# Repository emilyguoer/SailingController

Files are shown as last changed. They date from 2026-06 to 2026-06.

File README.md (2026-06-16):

## What is this project?

This project is a sailing boat controller. It uses a 3D printed boat model to simulate the rudder movement of a real sailing boat. The controller uses an M5Stack Atom as the main controller. Its built-in LED shows different states, such as Bluetooth connection, game mode, and calibration mode. Each M5Stack Chain Angle sensor is mounted inside a 3D printed boat shell.

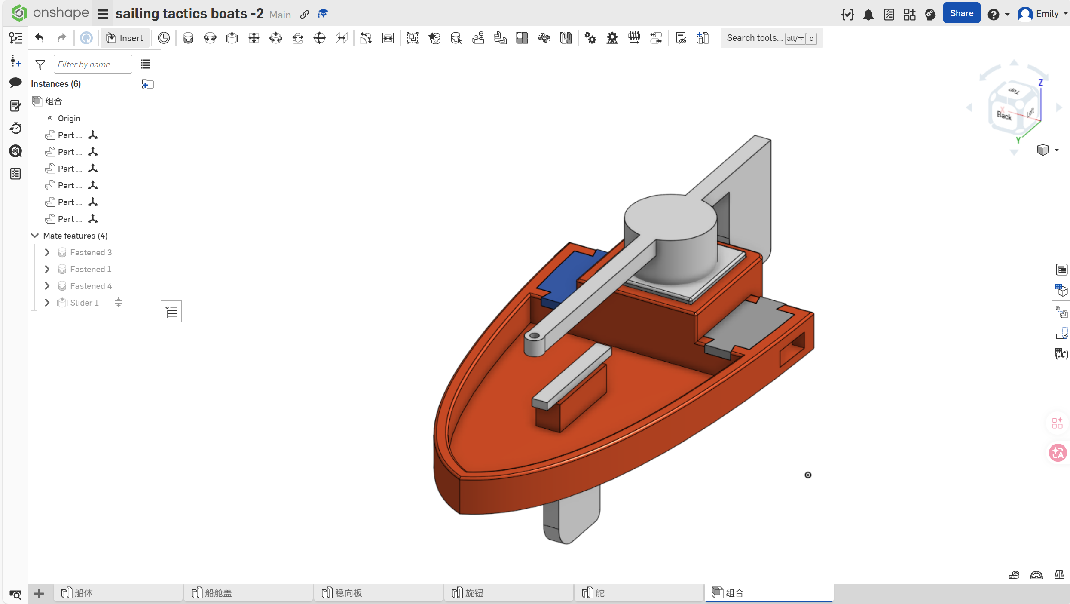
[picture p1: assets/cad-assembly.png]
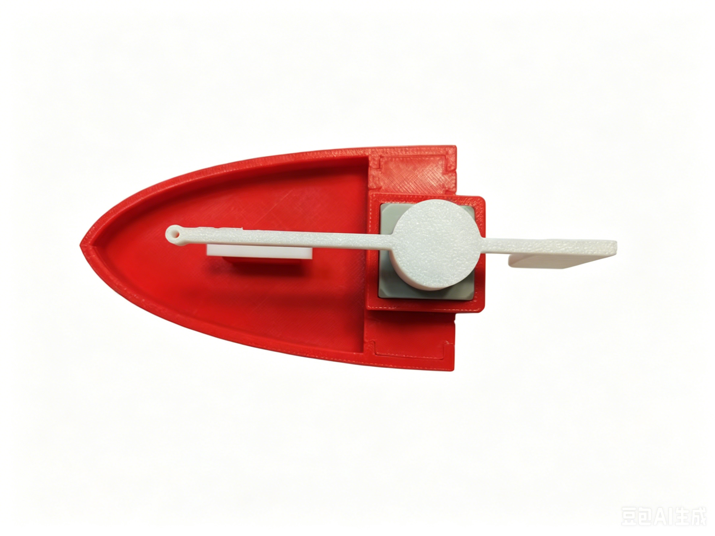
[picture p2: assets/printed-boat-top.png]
  

The M5Stack Chain Angle sensors work as the boat rudders. They read the rudder angle and convert the movement into keyboard inputs for Tactical Sailing.

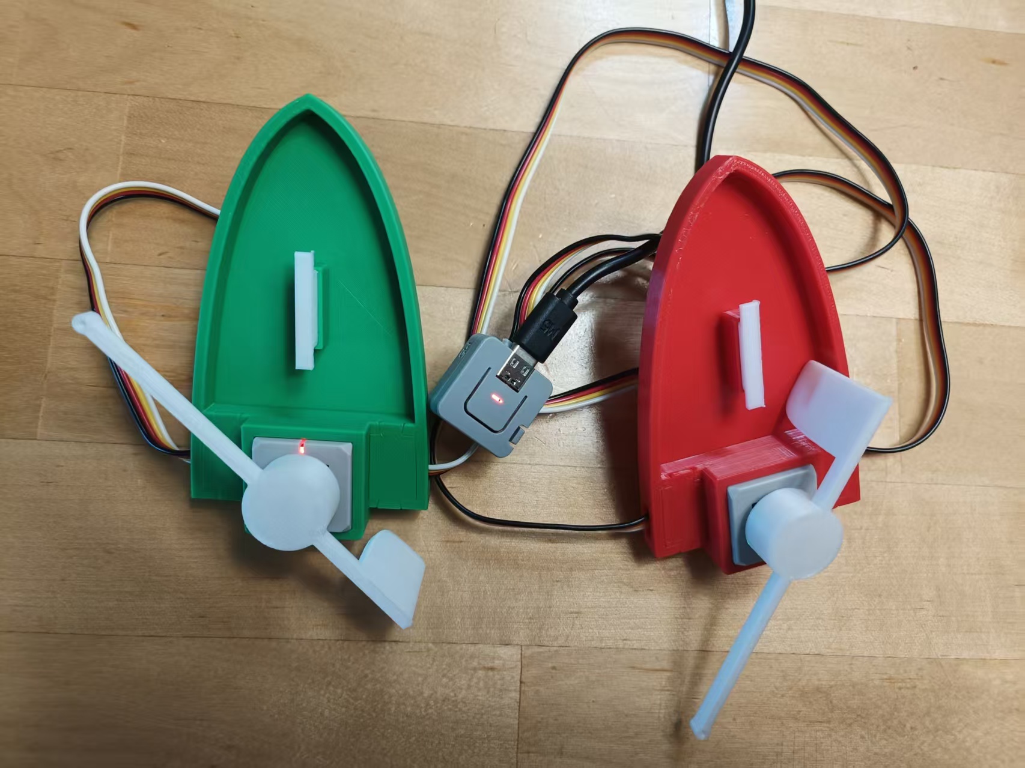
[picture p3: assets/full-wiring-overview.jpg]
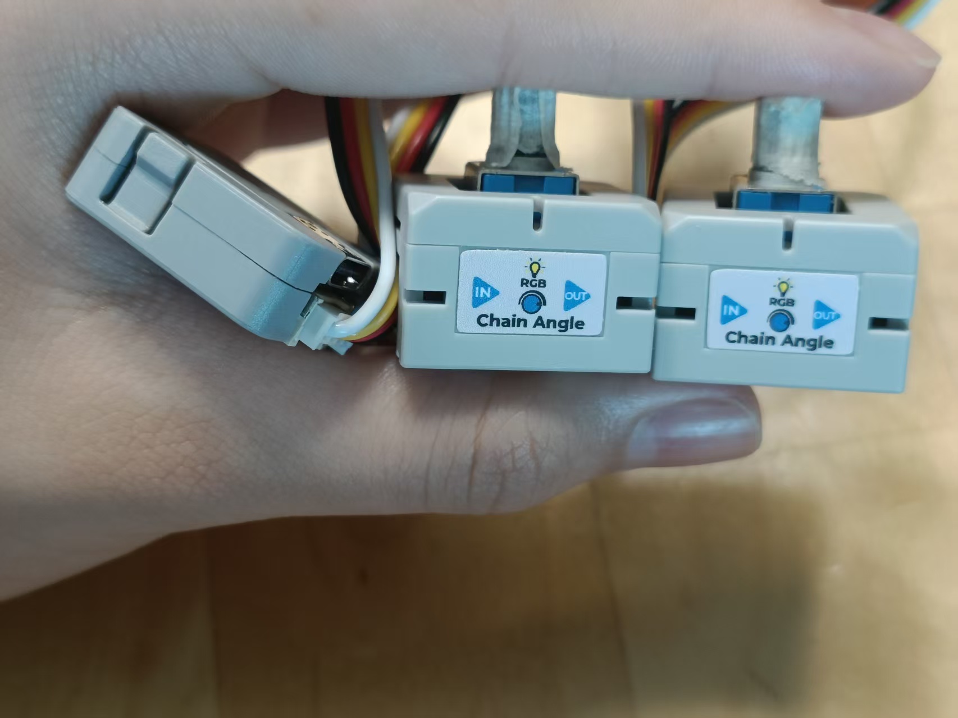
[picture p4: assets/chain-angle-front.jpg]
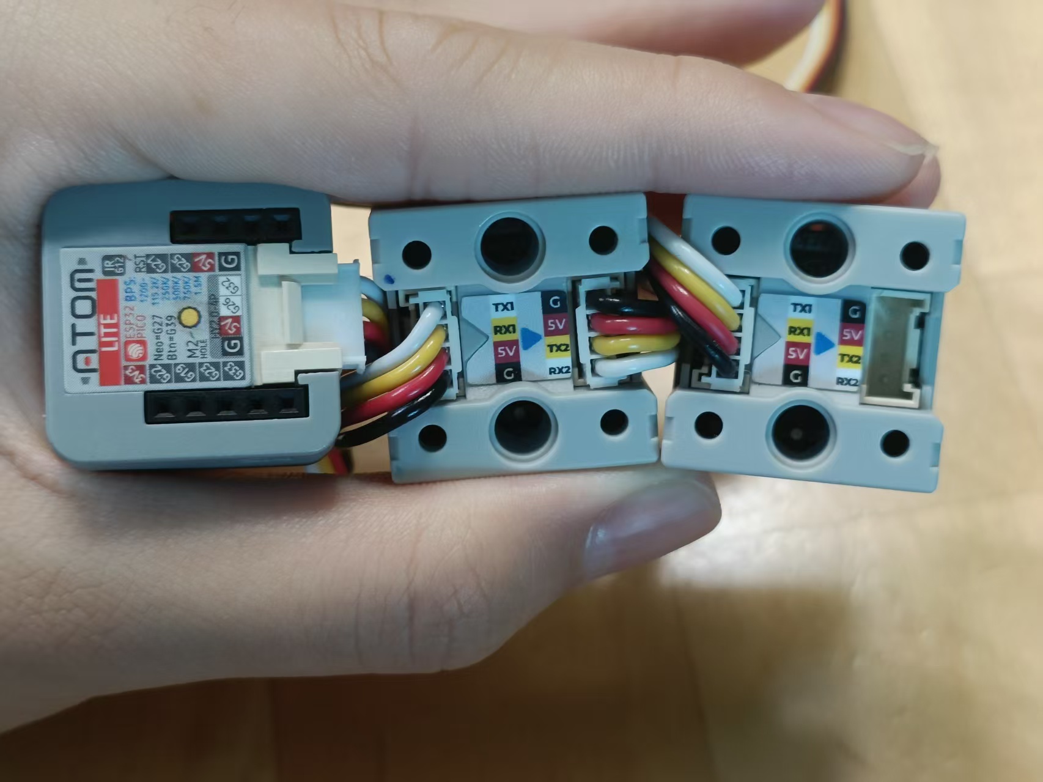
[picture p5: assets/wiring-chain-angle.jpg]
    

The M5Stack Chain Angle modules connect through the HY2.0-4P chain interface, so I do not need to wire each GPIO pin manually. The Atom Basic connects to the first Chain Angle module, then the OUT port of the first Chain Angle connects to the IN port of the second Chain Angle. The close-up photo shows the G / 5V / TX / RX labels next to the connector.

## How to use it

### 1. LED states

- Solid red: game mode is on and the controller is sending keyboard inputs
- Blinking yellow: Bluetooth is not connected / waiting for connection
- Blinking purple: angle zeroing / calibration mode
- Short cyan flash: calibration saved and exited successfully
- Blue: status indicator right after Bluetooth connects
- Teal: Bluetooth is connected, but game mode is off
- Short white flash: preparing to clear Bluetooth pairing and restart

### 2. Button controls

- Short press: turn game mode on or off
- Hold for 5 seconds: enter angle zeroing / calibration mode
- Double click during calibration mode: save the current angle as the center point and exit calibration
- Hold for 10 seconds: clear Bluetooth pairing and restart for re-pairing

### 3. Angle feedback

- The closer the knob is to the center, the brighter the light is
- The farther it moves away from the center, the dimmer the light is
- Brightness always stays at at least 20%

## What does it do?

- It can simulate boats in Tactical Sailing
- It lets players control the boat on screen using a physical rudder/knob
- It has game mode, calibration mode, and Bluetooth connection status
- It can calibrate the center position of the boat rudder
- It can connect two boat controllers, so two people can play the sailing game on one computer at the same time

## Design files and BOM

- Bill of Materials: [BOM.csv](BOM.csv)
- CAD source file: [shared Onshape design](https://cad.onshape.com/documents/45688ab7d551252db4da506c/w/4661672f9ede1a1bb0420ff5/e/e09c4bf824f8c0160060557d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)
- STEP file: [cad/AllBoat.step](cad/AllBoat.step)
- Zine PDF: [assets/sailing-tactic-poster.pdf](assets/sailing-tactic-poster.pdf)
- Firmware source code: [src/main_tactical_sailing.cpp](src/main_tactical_sailing.cpp)

## Why did I make it?

I often work as a sailing race judge in Hong Kong on weekends, so I am around sailing a lot. That gave me the idea to build a physical sailing controller that could help sailing clubs introduce the sport to new people. A club could put a large screen near its entrance, set up a few chairs, and let children or visitors control the boats in a computer sailing game using these small physical boat controllers.

This makes sailing easier to understand and more fun to try. It can also be useful on rainy days, when sailing club members cannot go out on the water but still want to practice sailing rules and basic control ideas. I think it can be a fun and useful teaching tool for sailing.

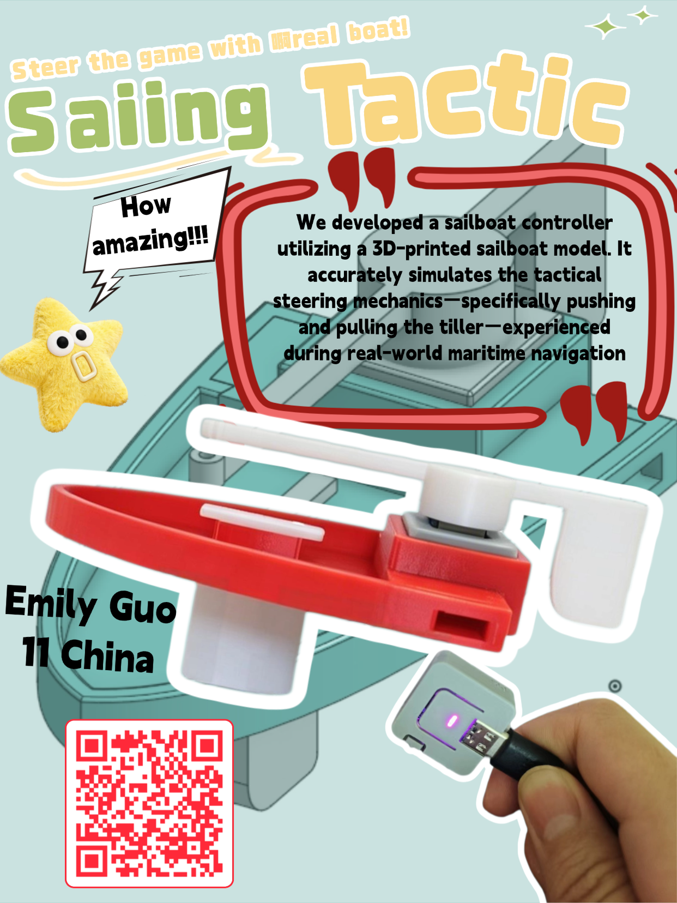
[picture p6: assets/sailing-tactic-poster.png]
Sailing Tactic Poster


## Demo video

[Open the demo video](assets/demo.mp4)

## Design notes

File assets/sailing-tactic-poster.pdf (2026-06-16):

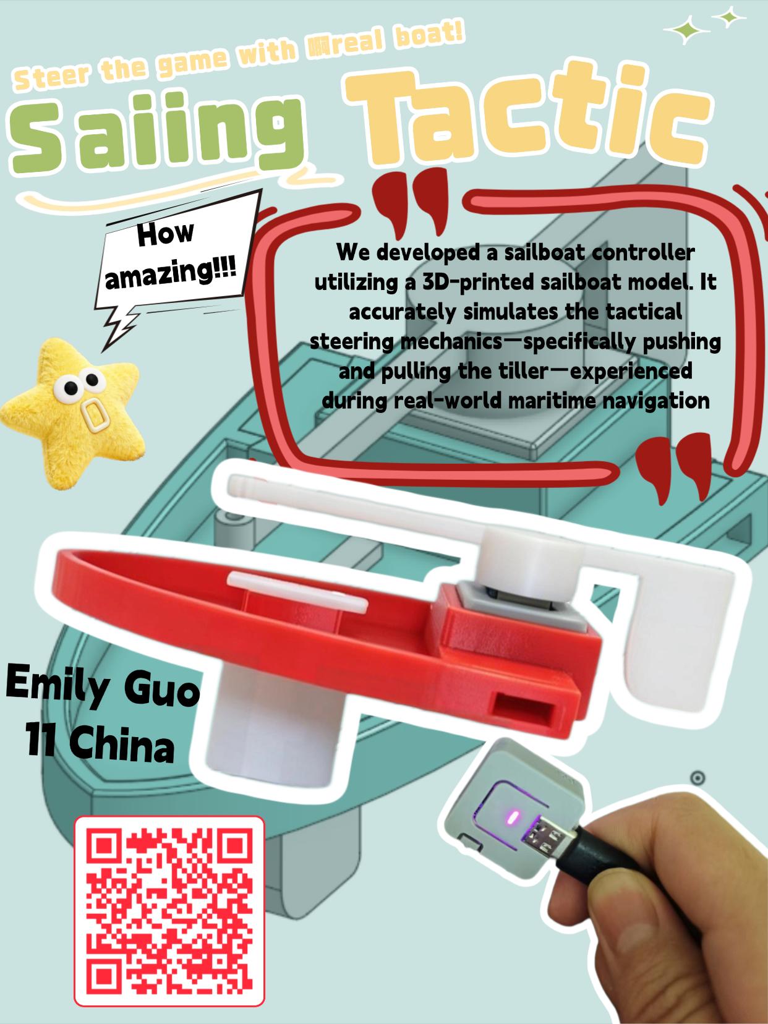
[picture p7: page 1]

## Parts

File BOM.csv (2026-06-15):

Item | Description | Quantity | Unit Cost (RMB) | Total Cost (RMB) | Source Link | Notes
M5Stack Chain Angle | Chain Angle sensor for rudder/knob input | 2 | 29 | 58 | https://shop.m5stack.com/products/chain-angle-stm32g031 | One sensor per boat controller
M5Stack Atom Basic / Atom Lite | ESP32 main controller | 1 | 79 | 79 | https://shop.m5stack.com/products/atom-lite-esp32-development-kit | Used as the BLE keyboard controller
M5Stack HY2.0-4P data cable | Data cable between Atom and Chain Angle modules | 2 | 10 | 20 | https://shop.m5stack.com/products/grove-y-cable-20cm-5pcs | Use matching M5Stack Grove/HY2.0-4P cable
3D printed boat shell | Custom printed boat body and controller enclosure | 1 | 0 | 0 | https://cad.onshape.com/documents/45688ab7d551252db4da506c/w/4661672f9ede1a1bb0420ff5/e/e09c4bf824f8c0160060557d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 | Self-printed with existing filament
3D printed rudder/knob/linkage | Custom printed steering parts for the Chain Angle sensor | 1 | 0 | 0 | https://cad.onshape.com/documents/45688ab7d551252db4da506c/w/4661672f9ede1a1bb0420ff5/e/e09c4bf824f8c0160060557d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 | Self-printed with existing filament
Total |  |  |  | 157 |  | Total estimated project cost in RMB

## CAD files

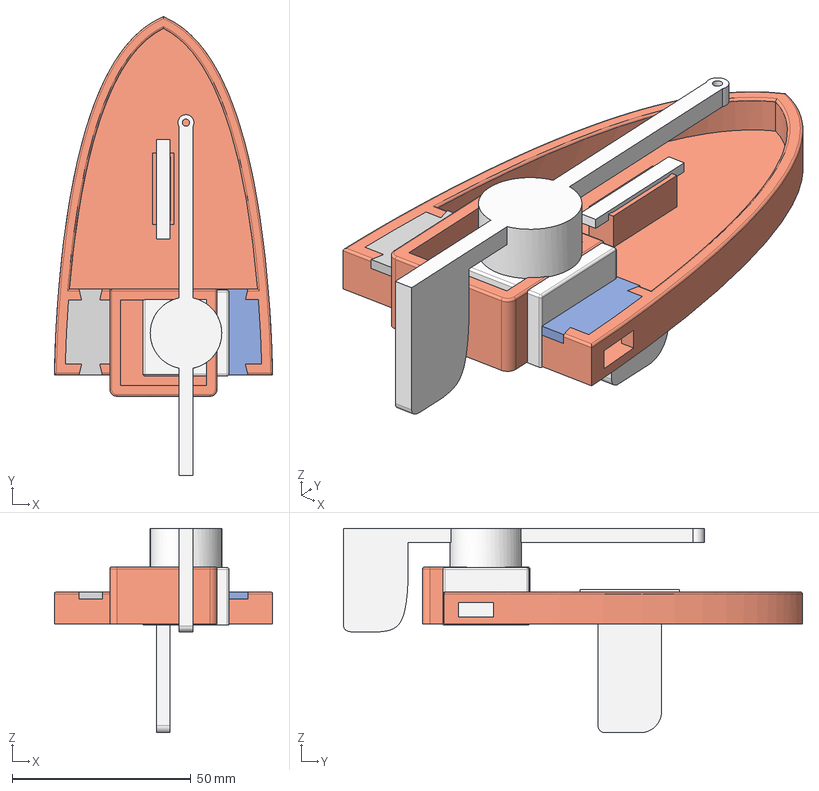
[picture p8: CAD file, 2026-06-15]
cad/AllBoat.step
61.0 x 128.3 x 57.2 mm

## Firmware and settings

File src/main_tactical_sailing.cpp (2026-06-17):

#include <Arduino.h>
#include <Adafruit_NeoPixel.h>
#include <BleKeyboard.h>
#include <M5Chain.h>
#include <Preferences.h>

#if defined(CONFIG_BT_BLUEDROID_ENABLED)
#include <esp_gap_ble_api.h>
#endif

namespace {

constexpr uint8_t kAtomLedPin = 27;
constexpr uint8_t kAtomLedCount = 1;
constexpr uint8_t kAtomButtonPin = 39;

constexpr int kChainRxPin = 32;
constexpr int kChainTxPin = 26;
constexpr uint32_t kChainBaud = 115200;

constexpr uint8_t kMaxSensors = 4;
constexpr uint32_t kSensorScanIntervalMs = 3000;
constexpr uint32_t kSensorReadIntervalMs = 10;
constexpr uint32_t kSensorLedUpdateIntervalMs = 250;
constexpr uint32_t kLedBlinkIntervalMs = 250;
constexpr uint32_t kDiagnosticPrintIntervalMs = 2000;
constexpr uint32_t kDebounceMs = 20;
constexpr uint32_t kDoubleClickWindowMs = 250;
constexpr uint32_t kCalibrationHoldMs = 5000;
constexpr uint32_t kPairingResetHoldMs = 10000;
constexpr uint32_t kConnectedIdleLedDelayMs = 10000;
constexpr uint32_t kTacticalKeyRepeatFastMs = 35;
constexpr uint32_t kTacticalKeyRepeatSlowMs = 100;

constexpr int16_t kAxisMin = -100;
constexpr int16_t kAxisMax = 100;
constexpr int16_t kAxisDeadzone = 2;
constexpr float kAdcCountsPerDegree = 4096.0f / 360.0f;
constexpr float kDefaultTravelDegrees = 45.0f;
constexpr int16_t kTravelAdcCounts = static_cast<int16_t>(kDefaultTravelDegrees * kAdcCountsPerDegree + 0.5f);
constexpr float kTacticalDeadzoneDegrees = 30.0f;
constexpr int16_t kTacticalKeyDeadzone =
    static_cast<int16_t>((kTacticalDeadzoneDegrees * 100.0f / kDefaultTravelDegrees) + 0.5f);

constexpr bool kAxisInvert[kMaxSensors] = {
    false,  // A1 / boat 1
    false,  // A2 / boat 2
    false,  // A3 / boat 3
    false,  // A4 / boat 4
};

struct Rgb {
  uint8_t r;
  uint8_t g;
  uint8_t b;
};

constexpr Rgb kSensorBaseColors[kMaxSensors] = {
    {255, 0, 0},    // A1: red
    {0, 255, 0},    // A2: green
    {255, 255, 0},  // A3: yellow
    {0, 0, 255},    // A4: blue
};

struct TacticalKeyPair {
  uint8_t left;
  uint8_t right;
};

constexpr TacticalKeyPair kTacticalKeys[kMaxSensors] = {
    {KEY_RIGHT_ARROW, KEY_LEFT_ARROW},  // A1
    {'x', 'v'},                         // A2
    {0, 0},
    {0, 0},
};

enum class Mode {
  Normal,
  AngleCalibration,
  PairingReset,
};

enum class ButtonEvent {
  None,
  SingleClick,
  DoubleClick,
  Hold5s,
  Hold10s,
};

Adafruit_NeoPixel atomLed(kAtomLedCount, kAtomLedPin, NEO_GRB + NEO_KHZ800);
Chain M5Chain;
BleKeyboard bleKeyboard("Tactical Sailing Boats", "M5Stack", 100);
Preferences prefs;

Mode mode = Mode::Normal;
uint16_t sensorIds[kMaxSensors] = {0};
uint16_t sensorCenters[kMaxSensors] = {2048, 2048, 2048, 2048};
uint16_t sensorRaw[kMaxSensors] = {2048, 2048, 2048, 2048};
uint8_t sensorCount = 0;

bool lastBleConnected = false;
bool bleEverConnected = false;
uint32_t bleConnectedAtMs = 0;
uint32_t lastSensorScanMs = 0;
uint32_t lastSensorReadMs = 0;
uint32_t lastSensorLedUpdateMs = 0;
uint32_t lastBlinkMs = 0;
uint32_t lastCalibrationRescanMs = 0;
uint32_t lastDiagnosticPrintMs = 0;
uint32_t lastKeyRepeatMs[kMaxSensors] = {0};
int8_t lastKeyDirection[kMaxSensors] = {0};
bool blinkOn = false;
bool ledRefreshDue = true;
bool gameActive = false;

bool stableButtonPressed = false;
bool lastRawButtonPressed = false;
uint32_t lastButtonRawChangeMs = 0;
uint32_t buttonPressedAtMs = 0;
uint32_t lastClickMs = 0;
uint8_t clickCount = 0;
bool hold5Reported = false;
bool hold10Reported = false;

uint32_t color(Rgb rgb) {
  return atomLed.Color(rgb.r, rgb.g, rgb.b);
}

void setAtomLed(Rgb rgb) {
  atomLed.setPixelColor(0, color(rgb));
  atomLed.show();
}

bool setSensorLed(uint16_t id, Rgb rgb) {
  uint8_t operationStatus = 0;
  uint8_t payload[3] = {rgb.r, rgb.g, rgb.b};
  chain_status_t status = M5Chain.setRGBLight(id, 100, &operationStatus);
  if (status != CHAIN_OK || !operationStatus) {
    Serial.printf("Angle LED brightness failed id=%u status=%u op=%u\r\n", id, status, operationStatus);
    return false;
  }

  operationStatus = 0;
  status = M5Chain.setRGBValue(id, 0, 1, payload, sizeof(payload), &operationStatus);
  if (status != CHAIN_OK || !operationStatus) {
    Serial.printf("Angle LED color failed id=%u status=%u op=%u\r\n", id, status, operationStatus);
    return false;
  }

  return true;
}

void setAllSensorLeds(Rgb rgb) {
  for (uint8_t i = 0; i < sensorCount; ++i) {
    setSensorLed(sensorIds[i], rgb);
  }
}

void sensorLedSelfTest() {
  if (sensorCount == 0) {
    return;
  }

  setAllSensorLeds({255, 0, 0});
  delay(250);
  setAllSensorLeds({0, 255, 0});
  delay(250);
  setAllSensorLeds({0, 0, 255});
  delay(250);
  setAllSensorLeds({0, 0, 0});
}

int16_t circularDelta12Bit(uint16_t value, uint16_t center) {
  int16_t delta = static_cast<int16_t>(value) - static_cast<int16_t>(center);
  if (delta > 2048) {
    delta -= 4096;
  } else if (delta < -2048) {
    delta += 4096;
  }
  return delta;
}

int16_t rawToAxis(uint8_t index, uint16_t value) {
  int32_t delta = circularDelta12Bit(value, sensorCenters[index]);
  if (kAxisInvert[index]) {
    delta = -delta;
  }

  int32_t mapped = (delta * 100L) / kTravelAdcCounts;
  mapped = constrain(mapped, kAxisMin, kAxisMax);
  if (abs(mapped) <= kAxisDeadzone) {
    mapped = 0;
  }
  return static_cast<int16_t>(mapped);
}

Rgb scaleColor(Rgb base, uint8_t brightness) {
  return {
      static_cast<uint8_t>((static_cast<uint16_t>(base.r) * brightness) / 255),
      static_cast<uint8_t>((static_cast<uint16_t>(base.g) * brightness) / 255),
      static_cast<uint8_t>((static_cast<uint16_t>(base.b) * brightness) / 255),
  };
}

uint8_t axisValueToBrightness(int16_t axisValue) {
  int16_t magnitude = abs(axisValue);
  magnitude = constrain(magnitude, 0, 100);
  return static_cast<uint8_t>(255 - ((255 - 51) * magnitude) / 100);
}

void updateSensorStatusLeds() {
  for (uint8_t i = 0; i < sensorCount && i < kMaxSensors; ++i) {
    int16_t axisValue = rawToAxis(i, sensorRaw[i]);
    uint8_t brightness = axisValueToBrightness(axisValue);
    setSensorLed(sensorIds[i], scaleColor(kSensorBaseColors[i], brightness));
  }
}

void loadCalibration() {
  prefs.begin("angle", true);
  for (uint8_t i = 0; i < kMaxSensors; ++i) {
    char key[8];
    snprintf(key, sizeof(key), "c%u", i);
    sensorCenters[i] = prefs.getUShort(key, 2048);
  }
  prefs.end();
}

void saveCalibrationFromCurrentAngles() {
  prefs.begin("angle", false);
  for (uint8_t i = 0; i < sensorCount && i < kMaxSensors; ++i) {
    sensorCenters[i] = sensorRaw[i];
    char key[8];
    snprintf(key, sizeof(key), "c%u", i);
    prefs.putUShort(key, sensorCenters[i]);
  }
  prefs.end();
}

void printSensorScanResult(const char *reason) {
  Serial.printf("%s: angle sensor count=%u\r\n", reason, sensorCount);
  Serial.println("Tactical Sailing key mode: A1=Left/Right, A2=V/X");
  for (uint8_t i = 0; i < sensorCount; ++i) {
    Serial.printf("  angle[%u] id=%u raw=%u\r\n", i, sensorIds[i], sensorRaw[i]);
  }
}

void scanSensors(bool verbose = false) {
  uint8_t previousCount = sensorCount;

  if (!M5Chain.isDeviceConnected(3, 50)) {
    sensorCount = 0;
    if (verbose) {
      Serial.println("Chain scan: no device response");
    } else if (previousCount != sensorCount) {
      Serial.println("Chain sensors disconnected");
    }
    return;
  }

  uint16_t deviceCount = 0;
  chain_status_t status = M5Chain.getDeviceNum(&deviceCount, 300);
  if (status != CHAIN_OK || deviceCount == 0) {
    sensorCount = 0;
    if (verbose) {
      Serial.printf("Chain scan: getDeviceNum failed status=%u count=%u\r\n", status, deviceCount);
    } else if (previousCount != sensorCount) {
      Serial.printf("No chain devices found status=%u\r\n", status);
    }
    return;
  }

  device_list_t deviceList;
  device_info_t devices[16];
  deviceList.count = min<uint16_t>(deviceCount, 16);
  deviceList.devices = devices;

  if (!M5Chain.getDeviceList(&deviceList, 500)) {
    sensorCount = 0;
    if (verbose) {
      Serial.printf("Chain scan: getDeviceList failed, deviceCount=%u\r\n", deviceCount);
    } else if (previousCount != sensorCount) {
      Serial.println("Failed to get chain device list");
    }
    return;
  }

  sensorCount = 0;
  for (uint16_t i = 0; i < deviceList.count && sensorCount < kMaxSensors; ++i) {
    if (deviceList.devices[i].device_type == CHAIN_ANGLE_TYPE_CODE) {
      sensorIds[sensorCount++] = deviceList.devices[i].id;
    }
  }

  if (verbose || previousCount != sensorCount) {
    Serial.printf("Angle sensors found: %u / chain devices: %u\r\n", sensorCount, deviceList.count);
    Serial.println("Tactical Sailing key mode: A1=Left/Right, A2=V/X");
    for (uint8_t i = 0; i < sensorCount; ++i) {
      Serial.printf("  angle[%u] id=%u\r\n", i, sensorIds[i]);
    }
    ledRefreshDue = true;
  }
}

void readSensors() {
  uint8_t readCount = gameActive ? min<uint8_t>(sensorCount, 2) : sensorCount;
  for (uint8_t i = 0; i < readCount; ++i) {
    uint16_t value = sensorRaw[i];
    if (M5Chain.getAngle12BitAdc(sensorIds[i], &value, 10) == CHAIN_OK) {
      sensorRaw[i] = value;
    }
  }
}

uint32_t axisValueToKeyRepeatInterval(int16_t axisValue) {
  int16_t magnitude = abs(axisValue);
  magnitude = constrain(magnitude, kTacticalKeyDeadzone, 100);
  return map(magnitude, kTacticalKeyDeadzone, 100, kTacticalKeyRepeatSlowMs, kTacticalKeyRepeatFastMs);
}

void sendTacticalSailingKeys() {
  if (!gameActive || !bleKeyboard.isConnected()) {
    return;
  }

  uint32_t now = millis();
  for (uint8_t i = 0; i < sensorCount && i < 2; ++i) {
    int16_t axisValue = rawToAxis(i, sensorRaw[i]);
    int8_t direction = 0;
    if (axisValue <= -kTacticalKeyDeadzone) {
      direction = -1;
    } else if (axisValue >= kTacticalKeyDeadzone) {
      direction = 1;
    }

    if (direction == 0) {
      lastKeyDirection[i] = 0;
      continue;
    }

    uint32_t repeatInterval = axisValueToKeyRepeatInterval(axisValue);
    if (direction != lastKeyDirection[i] || (now - lastKeyRepeatMs[i]) >= repeatInterval) {
      TacticalKeyPair keys = kTacticalKeys[i];
      uint8_t key = direction < 0 ? keys.left : keys.right;
      if (key == 0) {
        continue;
      }
      bleKeyboard.write(key);
      lastKeyRepeatMs[i] = now;
      lastKeyDirection[i] = direction;
    }
  }
}

ButtonEvent updateButton() {
  bool rawPressed = digitalRead(kAtomButtonPin) == LOW;
  uint32_t now = millis();

  if (rawPressed != lastRawButtonPressed) {
    lastRawButtonPressed = rawPressed;
    lastButtonRawChangeMs = now;
  }

  if ((now - lastButtonRawChangeMs) < kDebounceMs || rawPressed == stableButtonPressed) {
    if (stableButtonPressed && !hold5Reported && (now - buttonPressedAtMs) >= kCalibrationHoldMs) {
      hold5Reported = true;
      return ButtonEvent::Hold5s;
    }
    if (stableButtonPressed && !hold10Reported && (now - buttonPressedAtMs) >= kPairingResetHoldMs) {
      hold10Reported = true;
      return ButtonEvent::Hold10s;
    }
    return ButtonEvent::None;
  }

  stableButtonPressed = rawPressed;
  if (stableButtonPressed) {
    buttonPressedAtMs = now;
    hold5Reported = false;
    hold10Reported = false;
    return ButtonEvent::None;
  }

  if (hold5Reported || hold10Reported) {
    clickCount = 0;
    return ButtonEvent::None;
  }

  if (mode == Mode::Normal) {
    clickCount = 0;
    return ButtonEvent::SingleClick;
  }

  if ((now - lastClickMs) > kDoubleClickWindowMs) {
    clickCount = 0;
  }
  lastClickMs = now;
  clickCount++;

  if (clickCount >= 2) {
    clickCount = 0;
    return ButtonEvent::DoubleClick;
  }

  return ButtonEvent::None;
}

void removeBleBonds() {
#if defined(CONFIG_BT_BLUEDROID_ENABLED)
  int deviceCount = esp_ble_get_bond_device_num();
  if (deviceCount <= 0) {
    return;
  }

  esp_ble_bond_dev_t *bondedDevices =
      static_cast<esp_ble_bond_dev_t *>(calloc(deviceCount, sizeof(esp_ble_bond_dev_t)));
  if (bondedDevices == nullptr) {
    return;
  }

  int listedDevices = deviceCount;
  if (esp_ble_get_bond_device_list(&listedDevices, bondedDevices) == ESP_OK) {
    for (int i = 0; i < listedDevices; ++i) {
      esp_ble_remove_bond_device(bondedDevices[i].bd_addr);
    }
  }

  free(bondedDevices);
#endif
}

void enterPairingReset() {
  mode = Mode::PairingReset;
  removeBleBonds();
  setAtomLed({80, 80, 80});
  delay(1000);
  ESP.restart();
}

void enterCalibrationMode() {
  Serial.println("Enter angle zero/calibration mode");
  mode = Mode::AngleCalibration;
  gameActive = false;
  scanSensors(true);
  Serial.printf("Calibration angle sensor count: %u\r\n", sensorCount);
  readSensors();
  lastBlinkMs = 0;
  lastCalibrationRescanMs = millis();
  blinkOn = false;
  ledRefreshDue = true;
}

void exitCalibrationMode() {
  Serial.println("Exit angle zero/calibration mode");
  saveCalibrationFromCurrentAngles();
  mode = Mode::Normal;
  setAtomLed({0, 80, 80});
  delay(700);
  ledRefreshDue = true;
}

void updateBleState() {
  bool connected = bleKeyboard.isConnected();
  if (connected != lastBleConnected) {
    Serial.printf("BLE state change: %s -> %s @%u\r\n",
                  lastBleConnected ? "connected" : "disconnected",
                  connected ? "connected" : "disconnected",
                  millis());
  }
  if (connected && !lastBleConnected) {
    bleEverConnected = true;
    bleConnectedAtMs = millis();
  }
  lastBleConnected = connected;
}

void updateLeds() {
  uint32_t now = millis();
  if ((now - lastBlinkMs) >= kLedBlinkIntervalMs) {
    lastBlinkMs = now;
    blinkOn = !blinkOn;
    ledRefreshDue = true;
  }

  if (mode == Mode::AngleCalibration) {
    setAtomLed(blinkOn ? Rgb{70, 0, 90} : Rgb{0, 0, 0});
    return;
  }

  if (gameActive) {
    setAtomLed({90, 0, 0});
    return;
  }

  if (!bleKeyboard.isConnected()) {
    setAtomLed(blinkOn ? Rgb{90, 55, 0} : Rgb{0, 0, 0});
    return;
  }

  if (bleEverConnected && (now - bleConnectedAtMs) >= kConnectedIdleLedDelayMs) {
    setAtomLed({0, 70, 35});
  } else {
    setAtomLed({0, 45, 90});
  }
}

void handleButtonEvent(ButtonEvent event) {
  switch (event) {
    case ButtonEvent::SingleClick:
      if (mode == Mode::Normal) {
        gameActive = !gameActive;
        memset(lastKeyDirection, 0, sizeof(lastKeyDirection));
        memset(lastKeyRepeatMs, 0, sizeof(lastKeyRepeatMs));
        Serial.printf("Game mode: %s\r\n", gameActive ? "ON" : "OFF");
      }
      break;

    case ButtonEvent::Hold5s:
      if (mode == Mode::Normal) {
        enterCalibrationMode();
      }
      break;

    case ButtonEvent::Hold10s:
      enterPairingReset();
      break;

    case ButtonEvent::DoubleClick:
      if (mode == Mode::AngleCalibration) {
        exitCalibrationMode();
      }
      break;

    case ButtonEvent::None:
      break;
  }
}

}  // namespace

void setup() {
  Serial.begin(115200);
  delay(1500);
  Serial.println();
  Serial.println("Boat Angle Controller boot");
  Serial.printf("Chain UART: RX=%d TX=%d baud=%lu\r\n", kChainRxPin, kChainTxPin,
                static_cast<unsigned long>(kChainBaud));

  pinMode(kAtomButtonPin, INPUT);
  atomLed.begin();
  atomLed.setBrightness(80);
  setAtomLed({0, 0, 20});

  loadCalibration();

  M5Chain.begin(&Serial2, kChainBaud, kChainRxPin, kChainTxPin);
  delay(300);
  scanSensors(true);
  readSensors();
  printSensorScanResult("Boot scan");
  updateSensorStatusLeds();

  Serial.println("BLE keyboard init");
  bleKeyboard.begin();
}

void loop() {
  uint32_t now = millis();

  handleButtonEvent(updateButton());
  updateBleState();

  if (!gameActive && (now - lastSensorScanMs) >= kSensorScanIntervalMs) {
    lastSensorScanMs = now;
    scanSensors();
  }

  if (mode == Mode::AngleCalibration && sensorCount == 0 &&
      (now - lastCalibrationRescanMs) >= kSensorScanIntervalMs) {
    lastCalibrationRescanMs = now;
    scanSensors(true);
  }

  if (!gameActive && (now - lastDiagnosticPrintMs) >= kDiagnosticPrintIntervalMs) {
    lastDiagnosticPrintMs = now;
    Serial.printf("Diag: mode=%u game=%u button=%u angles=%u ble=%u\r\n", static_cast<unsigned>(mode), gameActive,
                  digitalRead(kAtomButtonPin) == LOW, sensorCount, bleKeyboard.isConnected());
  }

  if ((now - lastSensorReadMs) >= kSensorReadIntervalMs) {
    lastSensorReadMs = now;
    readSensors();
  }

  if (mode == Mode::Normal) {
    sendTacticalSailingKeys();
  }

  if (!gameActive && (now - lastSensorLedUpdateMs) >= kSensorLedUpdateIntervalMs) {
    lastSensorLedUpdateMs = now;
    updateSensorStatusLeds();
  }

  updateLeds();
  delay(2);
}

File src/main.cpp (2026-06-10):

#include <Arduino.h>
#include <Adafruit_NeoPixel.h>
#include <M5Chain.h>

constexpr uint8_t kAtomLedPin = 27;
constexpr uint8_t kAtomLedCount = 1;
constexpr uint8_t kAtomButtonPin = 39;

constexpr int kChainRxPin = 32;
constexpr int kChainTxPin = 26;
constexpr uint32_t kChainBaud = 115200;

constexpr uint32_t kBreathStepIntervalMs = 30;
constexpr uint32_t kSensorScanIntervalMs = 3000;
constexpr uint32_t kSensorReadIntervalMs = 20;
constexpr int16_t kUnlockDegrees = 10;
constexpr int16_t kCountsPerUnlockDegrees = static_cast<int16_t>(4096L * kUnlockDegrees / 360L);

Adafruit_NeoPixel atomLed(kAtomLedCount, kAtomLedPin, NEO_GRB + NEO_KHZ800);
Chain M5Chain;

bool hasSensor = false;
uint16_t sensorId = 0;
uint16_t latestRawAngle = 2048;
uint16_t blueStartRawAngle = 2048;
bool blueLocked = false;
bool lastButtonPressed = false;

uint8_t breathBrightness = 0;
int8_t breathDirection = 1;
uint32_t lastBreathStepMs = 0;
uint32_t lastSensorScanMs = 0;
uint32_t lastSensorReadMs = 0;

void setAtomLed(uint8_t r, uint8_t g, uint8_t b, uint8_t brightness) {
  atomLed.setBrightness(brightness);
  atomLed.setPixelColor(0, atomLed.Color(r, g, b));
  atomLed.show();
}

int16_t angleDelta12Bit(uint16_t current, uint16_t start) {
  int16_t delta = static_cast<int16_t>(current) - static_cast<int16_t>(start);
  if (delta > 2048) {
    delta -= 4096;
  } else if (delta < -2048) {
    delta += 4096;
  }
  return delta;
}

void scanSensor() {
  hasSensor = false;
  sensorId = 0;

  if (!M5Chain.isDeviceConnected(3, 50)) {
    return;
  }

  uint16_t deviceCount = 0;
  if (M5Chain.getDeviceNum(&deviceCount, 300) != CHAIN_OK || deviceCount == 0) {
    return;
  }

  device_info_t devices[16];
  device_list_t deviceList;
  deviceList.count = min<uint16_t>(deviceCount, 16);
  deviceList.devices = devices;

  if (!M5Chain.getDeviceList(&deviceList, 500)) {
    return;
  }

  for (uint16_t i = 0; i < deviceList.count; ++i) {
    if (deviceList.devices[i].device_type == CHAIN_ANGLE_TYPE_CODE) {
      sensorId = deviceList.devices[i].id;
      hasSensor = true;
      return;
    }
  }
}

void updateSensor() {
  if (!hasSensor) {
    return;
  }

  uint16_t rawAngle = latestRawAngle;
  if (M5Chain.getAngle12BitAdc(sensorId, &rawAngle) == CHAIN_OK) {
    latestRawAngle = rawAngle;
  }
}

void updateBreathingLed(uint32_t now) {
  if ((now - lastBreathStepMs) < kBreathStepIntervalMs) {
    return;
  }

  lastBreathStepMs = now;
  setAtomLed(150, 50, 80, breathBrightness);

  if (breathDirection > 0 && breathBrightness >= 100) {
    breathDirection = -1;
  } else if (breathDirection < 0 && breathBrightness == 0) {
    breathDirection = 1;
  }

  breathBrightness = static_cast<uint8_t>(breathBrightness + breathDirection);
}

void setup() {
  Serial.begin(115200);
  pinMode(kAtomButtonPin, INPUT);

  atomLed.begin();
  atomLed.clear();
  atomLed.show();

  M5Chain.begin(&Serial2, kChainBaud, kChainRxPin, kChainTxPin);
  delay(300);
  scanSensor();
  updateSensor();
}

void loop() {
  uint32_t now = millis();
  bool buttonPressed = digitalRead(kAtomButtonPin) == LOW;

  if ((now - lastSensorScanMs) >= kSensorScanIntervalMs) {
    lastSensorScanMs = now;
    scanSensor();
  }

  if ((now - lastSensorReadMs) >= kSensorReadIntervalMs) {
    lastSensorReadMs = now;
    updateSensor();
  }

  if (buttonPressed && !lastButtonPressed) {
    blueLocked = true;
    blueStartRawAngle = latestRawAngle;
    setAtomLed(100, 70, 180, 100);
  }
  lastButtonPressed = buttonPressed;

  if (blueLocked) {
    setAtomLed(100, 70, 180, 100);

    int16_t delta = angleDelta12Bit(latestRawAngle, blueStartRawAngle);
    if (abs(delta) >= kCountsPerUnlockDegrees) {
      blueLocked = false;
    }
  } else {
    updateBreathingLed(now);
  }

  delay(2);
}

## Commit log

2026-06-13 写了一半瑞德面
2026-06-15 Prepare Fallout design submission assets
    [AllBoat.step, BOM.csv]
